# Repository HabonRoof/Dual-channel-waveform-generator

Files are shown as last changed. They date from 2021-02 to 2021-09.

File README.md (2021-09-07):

# 基於AD9833之雙通道直接數位合成波型產生器

## 簡介  

本專案使用AD9833直接數位信號合成器(Direct Digital Synthesizer)，利用數位方式產生任意波型與頻率。  
控制端使用與Arduino UNO相同之Atmega328P微處理器，顯示器使用128*64藍底白字LCD顯示器。  
This projec use AD9833 direct digital synthesizer to generate any waveform with any frequency.
Atmega328P as main controller, and the white blue LCD display shows the user interface.
使用方法:
首先透過LCD螢幕設定各通道之波型、頻率、相位等等參數，透過微處理器設定參數，再由AD9833產生對應之波型訊號。  
此訊號會再透過LM318 高轉動率(Slew Rate)運算放大器將電壓放大至+12V~-12V之振幅。  
此外，板載之+12、-12、5V電源使用線性穩壓器做為電源供應，提供乾淨無雜訊之直流電源，以避免市電雜訊干擾波型輸出。  
How to use:
Use the rotary encode to setup th ewaveform parameter, such as waveform type, frequency and phase, which progress to main uC, and generate the corresponding sugnal.
The signal will megnified by LM318 high slew-rate amplifier to +12V~-12V range.
Morevoer, the project use low dropout linear regulater to provide clar, noise-less power source.

## 波型展示
最高頻率輸出/Maximum frequency output  
12.5 MHz 輸出
最低頻率輸出  

正弦波/Sinusoidal wave  
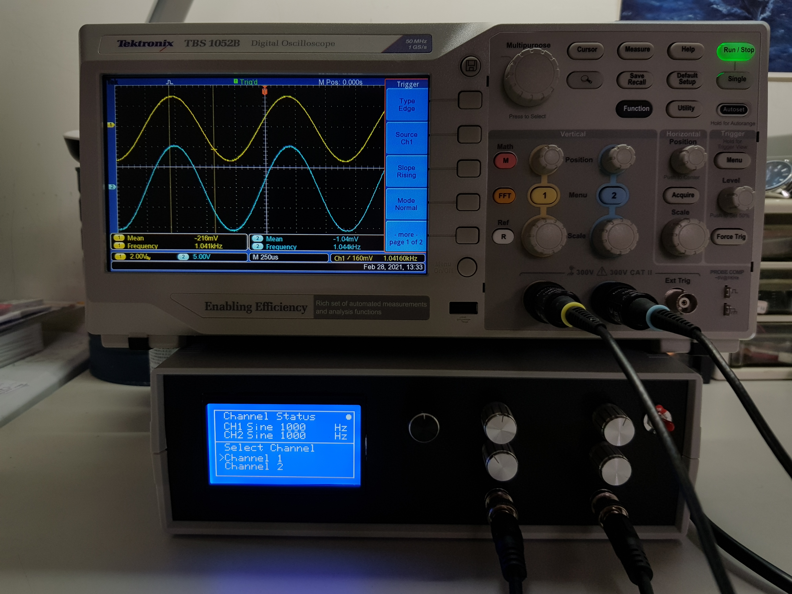
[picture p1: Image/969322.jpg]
6kHz 正弦波輸出

方波
1kHz 方波輸出
三角波/Truangular wave
1kHz 三角波輸出
主選單畫面/Main menu
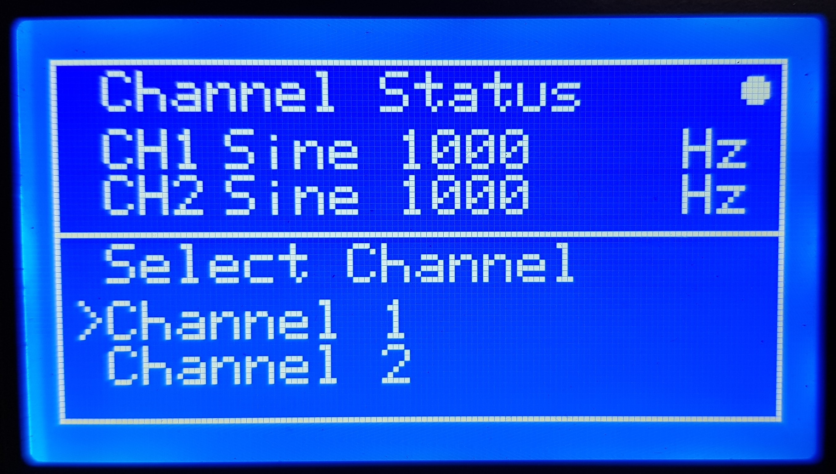
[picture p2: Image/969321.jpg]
通道輸出狀態以及主選單

通道1 設定選擇畫面/Channel1 setting
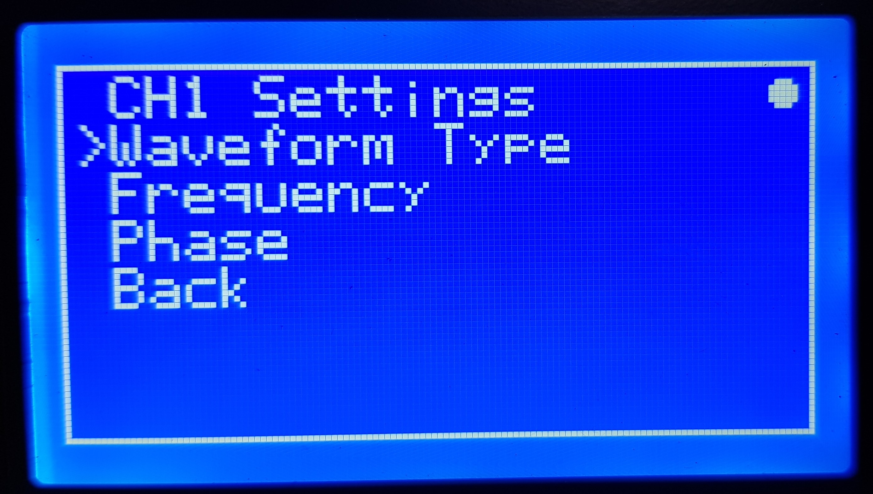
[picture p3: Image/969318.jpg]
Ch1 設定

波型選擇畫面/Waveform types
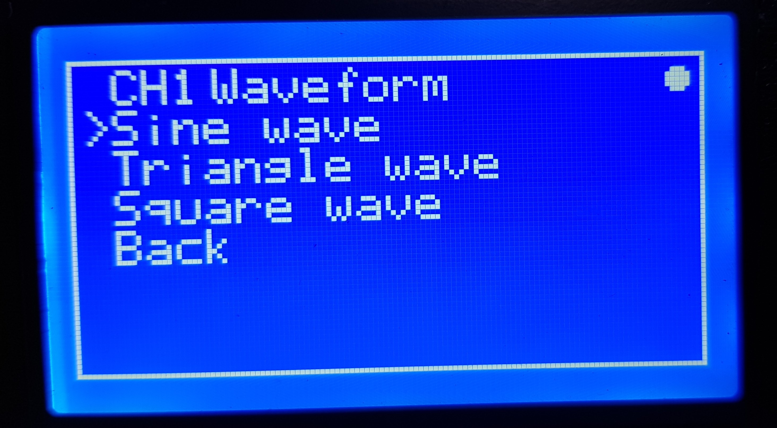
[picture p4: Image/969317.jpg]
CH1波型選擇

頻率設定畫面/Frequency setting
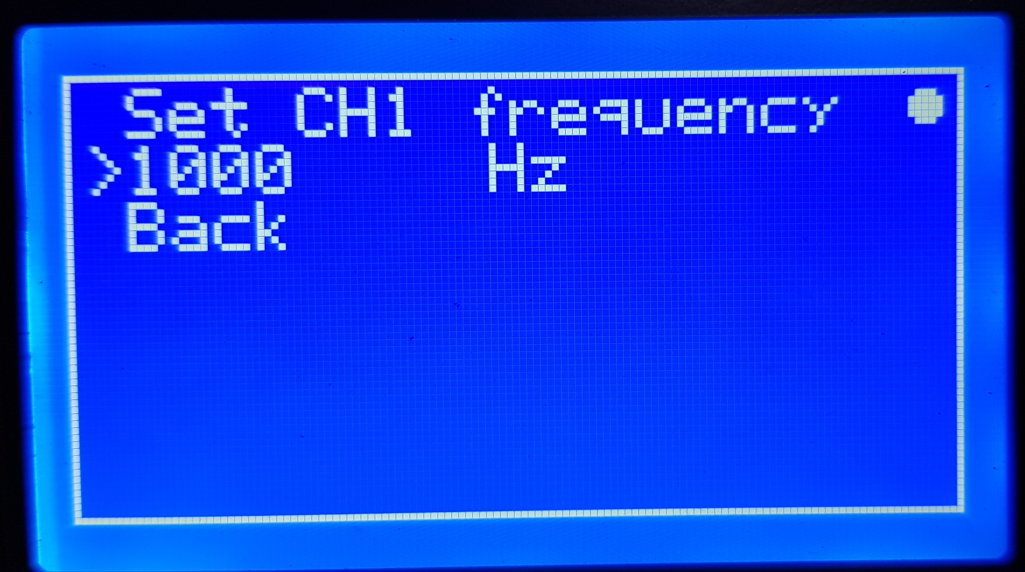
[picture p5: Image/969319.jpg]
Ch1頻率設定

頻率設定畫面-2/Frequency Setting
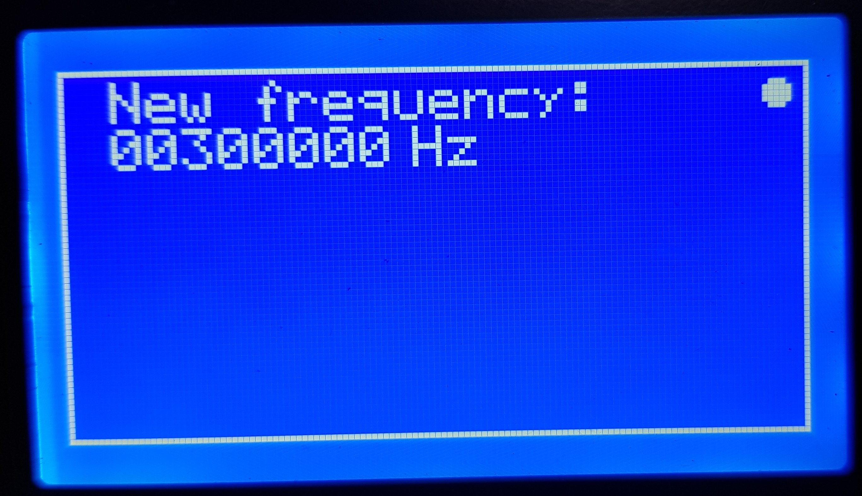
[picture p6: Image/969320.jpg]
Ch1頻率設定畫面-2


##材料表
AD9833 DDS Module x2   
Atmega328P x1  
LM318 運算放大器 x2  
12W 110/220V轉12Vac 變壓器 x1  
10k Ohm 可變電阻 x2  
100k Ohm 可變電阻 x2  
旋轉編碼器 x1  
開關 x2  
專案盒 x1  
電容器 x6  

## 硬體介紹
###AD9833 DDS 訊號產生器  
[維基百科-直接數位訊號合成](https://zh.wikipedia.org/wiki/%E7%9B%B4%E6%8E%A5%E6%95%B0%E5%AD%97%E5%90%88%E6%88%90)  
[Digikey-直接數位合成器-基本知識](https://www.digikey.tw/zh/articles/the-basics-of-direct-digital-synthesizers-ddss)  
直接數位訊號合成器基本原理就是使用內建的數位訊號表，紀錄不同訊號的波型振福， 
晶片讀取波型振福後，利用自身的類比數位訊號轉換器將資料轉換成實際電壓輸出，進而模擬出連續的類比訊號。  
然而，受限於最大系統時脈頻率，最高的模擬波型輸出頻率只有系統時脈頻率的1/2，此為奈奎氏頻率的限制，  
但可以更簡單的理解成在方波的情況下，波型有兩種狀況:最大與最小，而假設系統時脈頻率為fs，輸出頻率最大也只能到1/2 fs。  
DDS雖然可以透過查表產生不同波型，但其本質仍然是使用方波座數位訊號合成，因此在輸出波型中會含有系統時脈的諧波成分，  
要解決此問題需要在輸出端放置一低通濾波器將高頻諧波截去。此濾波器截止頻率需設定稍高於最大輸出頻率，即1/2 fs。
更詳細的原理可以參考上方超連結。  

###LM318 運算放大器  
電子電路中，運算放大器為常見的使用零件，但在基礎實習應用或比較器應用中，較不重視轉動率(Slew Rate)這項參數。  
此參數是評價運算放大器速度的重要指標，其定義為: 單位時間內可變化的電壓大小，單位為 V/uS。
在本專案一開始，使用LM358 作為訊號放大器，但其轉動率只有0.3V/uS，其較慢的轉動率使的DDS產生高頻訊號時，無法放大輸入訊號，導致輸出訊號震幅降低。  
後來改使用LM318訊號放大器後，其轉動率為70V/uS，此特性雖不足以滿足我們最高頻率12.5MHz，最大峰對峰值24V之設計，但可計算出在1MHz輸出下，電壓震幅可達7V之特性。  
這已經滿足大部分的應用需求了。  

###Atmega 328P 8位元微處理器  
大家熟悉的Arduino UNO就是使用這顆微控制器，本專案使用Atmega328P最精簡電路，並透過USB-TTL 燒錄器將程式碼燒錄進晶片中。  
Atmega最精簡電路只需要16MHz石英晶體震盪器、2x22pF陶瓷電容器、按鈕開關以及10k Ohm電阻即可建構。  
燒錄器可選擇任意USB5轉TTL串列埠訊號轉換器，在電腦端安裝好轉換器的驅動程式後，使用Arduino IDE燒錄時，當狀態是列顯示"上傳中" 時，按下重製按鈕便可將程式碼上傳至微處理機中。

###12864LCD液晶顯示器  
此液晶顯示器與市面上常見之128X64液晶顯示器稍微不同，因為是從對岸採購的，所以其函式庫

## 軟體介紹
firmware_v1.0 .ino  
第1.0版本波型產生器主要程式，

lcd_screens.ino  
液晶顯示器特定頁面  

lcdUI.h  
LCD目錄子函式，包含主目錄、通道設定、波型選擇、頻率選擇、相位選擇。  
此項目專攻coding的人看到會發瘋，因為我亂用class級別 QQ  
照理說可以再把這部分簡化，或者直接用子程式取代即可。  

## 已知問題
1. 此波型產生器之最高頻率為12.5MHz(方波，系統頻率為24MHz時)，受限於V1.0版本資料型態以及變數設置，最大只有10MHz，仍待改進。
2. 選單主畫面缺乏目前通道訊號狀態
3. 線性穩壓器溫度需要量測
4. V1.0版尚未支援波型相位設定
5. 實際輸出與設定值似乎有誤差，檢查lcdSetFrequency涵式

##改進目標
1. 功率消耗過高，浪費在線性穩壓器上
2. 硬體忘記留韌體燒錄孔 QwQ 每次都要拆開更新韌體

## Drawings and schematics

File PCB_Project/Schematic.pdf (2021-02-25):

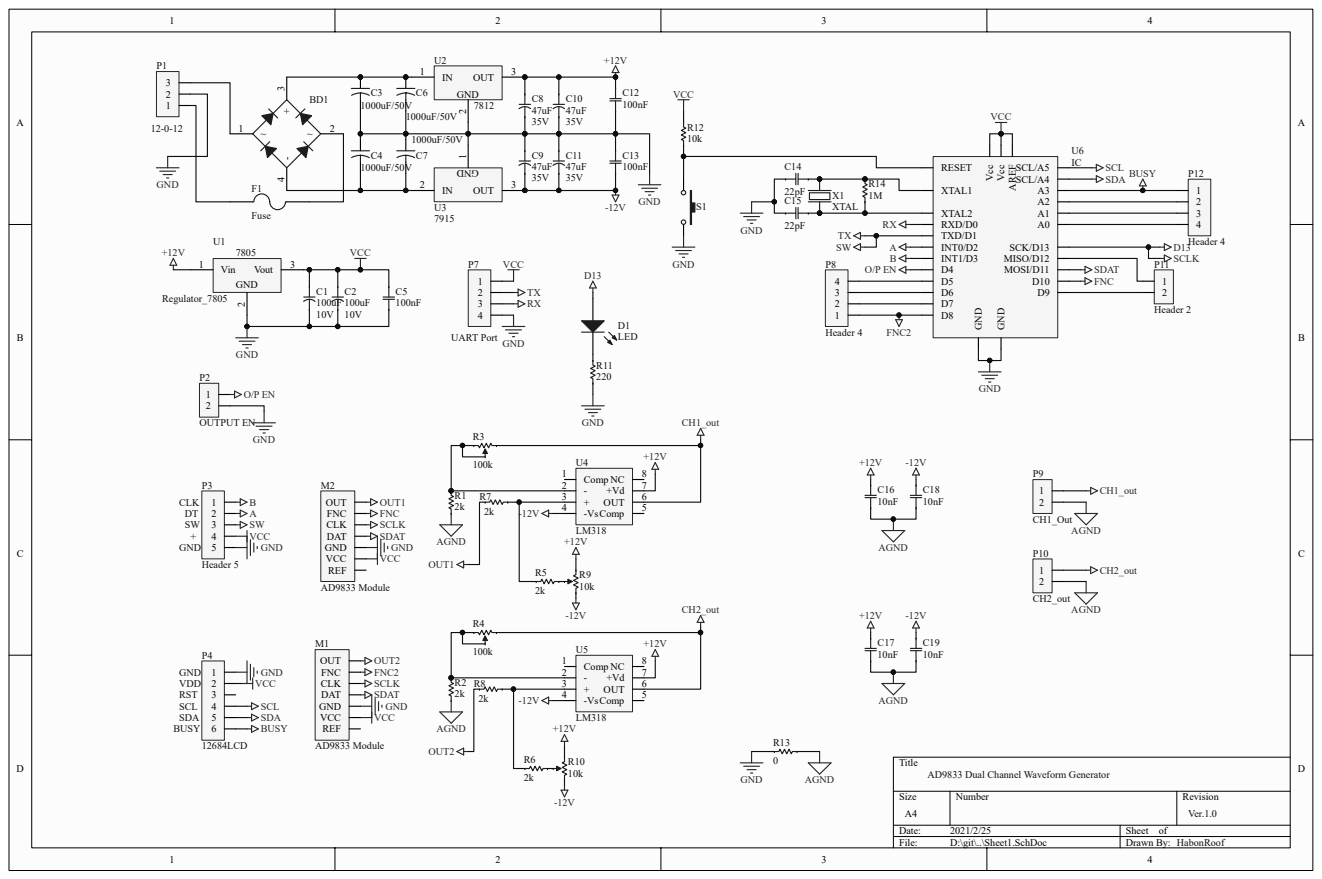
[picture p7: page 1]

Title
AD9833 Dual Channel Waveform Generator

Date: 2021/2/25 | Sheet of
File: D:\git\..\Sheet1.SchDoc | Drawn By: HabonRoof

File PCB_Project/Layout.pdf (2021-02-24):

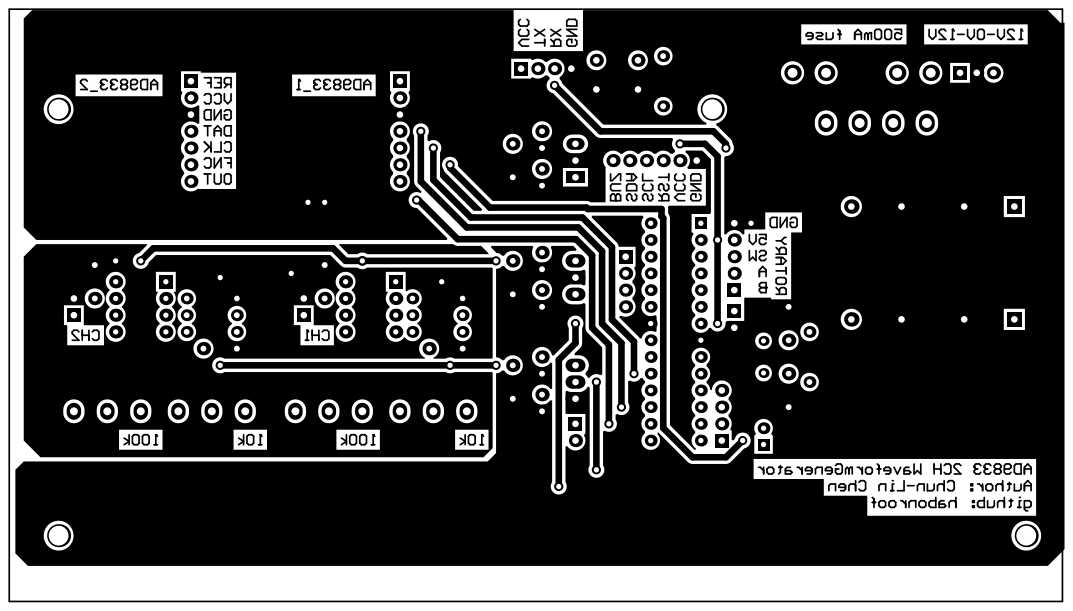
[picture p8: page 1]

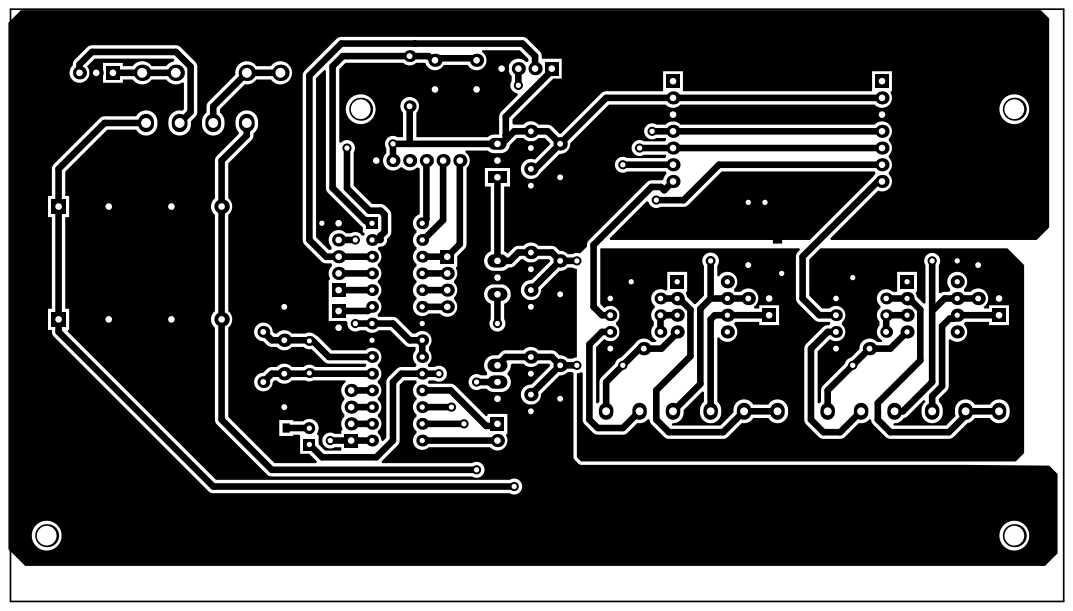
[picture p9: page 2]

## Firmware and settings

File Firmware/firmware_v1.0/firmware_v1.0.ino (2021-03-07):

/*
  This is a dual channel wave form generator firmware
  Use AD9833 DDS signal generator as main function IC
  Hardware schematic please visit @habonroof github

  Author: Chun-Lin Chen (HabonRoof)
  License: CC-BY 3.0

  Update: 2021/02/28
  Feature:Add channel status page at main menu
  Fix the accurate of frequency issue
  Add channel indicator on each setting screen to ensure user know which channel is he setting
  Issue:
  Phase function not avaliable
  The USB-TTL cable will interference the module signal, but not effect at output.
*/

#include <AD9833.h>         //Include AD9833 library from BillWilliams1952 @https://github.com/Billwilliams1952/AD9833-Library-Arduino
#include <RSCG12864B.h>     //Include RSCG12864 LCD module library. If you use another LCD, please modify the library as your LCD display.
#include <RotaryEncoder.h>  //Include awesome rotary encoder library from mathertel @https://github.com/brianlow/Rotary
#include "lcdUI.h"

//------------------ Pin configuration ----------------------

#define FNC_PIN     10      // Function pin of first AD9833 module
#define FNC_PIN2    8       // Function pin of second AD9833 module
#define Enable      4       // Enable output
#define Enter       1       // Rotary encoder button

RotaryEncoder encoder(2, 3);// Rotary encoder connect pin. I converte the pins into "pin change interrupt" mode to responce faster



//------------------- Create an AD9833 object ---------------

// Note, SCK and MOSI must be connected to CLK and DAT pins on the AD9833 for SPI
AD9833 gen(FNC_PIN, 24000000);       //Declare gen object as first AD9833 module
AD9833 gen2(FNC_PIN2, 24000000);     //Declare gen2 object as second AD9833 module

float ch1Freq = 1000.0;
float ch1Phase = 0;

float ch2Freq = 1000.0;
float ch2Phase = 0;
bool ad9833Update = false;

//--------------------- Serial Debug ------------------------

#define DEBUG  1    // 1:Enable Serial debugging 0:disable

//---------------------- Useful flags -----------------------

bool switchState = false;
bool lcdNeedUpdate = true;


//----------------------- UI variable ------------------------

int rotaryCtr = 0;
int buttonCtr = 0;
int oldButtonCtr = 0;
byte layer1Item = 0;
byte layer2Item = 0;
byte layer3Item = 0;
byte layer1Temp = 0;
byte layer2Temp = 0;
byte layer3Temp = 0;
bool back = false;
bool resetFlag = false;
bool setFreq = false;
bool setPhase = false;
float newFreq = 0.0;
byte ch1Waveform = 0;   //0 = sine, 1 = triangle, 2 = square
byte ch2Waveform = 0;

menuPage1 mainMenu;
menuPage2 channel;
menuPage3 waveform;
menuPage4 frequency;
menuPage5 phase;


void lcdShowMenu();
void lcdBootScreen();
void lcdAboutScreen();
void lcdSetFrequency();


//---------------------- Debounce --------------------------

unsigned long lastButtonPress = 0;
bool lastButtonState = true;
bool buttonState = true;

//---------------------- Sub function -----------------------

void ad9833Init();
void lcdBootScreen();   //Indicate the boot screen
void buttonChecker();   //Check the button and the rotary encoder
bool buttonPress();     //If button pressed, return true
void rotaryChecker();   //Check the rotary encoder value
void lcdShowMenu();
void ad9833Run();    //Update the AD9833 module for new configuration
void outputChecker();   //Check the output switch
void resetMenuItem();
unsigned long power();  //instead using pow()function because there is an error instead accurate value

//------------------------ ISR --------------------------------

ISR(PCINT2_vect) {
  encoder.tick();
}

//------------------------ Setup -----------------------------

void setup() {
#ifdef DEBUG
  Serial.begin(115200);
#endif

  PCICR   |= (1 << PCIE2);    // Enables Pin Change Interrupt 1 that covers the Analog input pins or Port C.
  PCMSK2  |= (1 << PCINT18) | (1 << PCINT19);  // This enables the interrupt for pin 2 and 3 of Port C.

  pinMode(Enable, INPUT_PULLUP);
  pinMode(Enter, INPUT);
  RSCG12864B.begin();
  RSCG12864B.brightness(255);
  RSCG12864B.clear();
  ad9833Init();
  lcdBootScreen();
  lastButtonPress = millis();   //Set last button press time to millis()
}

//----------------------- Main loop --------------------------------

void loop() {
  outputChecker();    // Enable oputput
  buttonChecker();
  rotaryChecker();
  lcdShowMenu();
  ad9833Run();
  resetMenuItem();
#ifdef DEBUG
  Serial.print("setFreq:");
  Serial.println(setFreq);
  Serial.print("oldButtonCtr:");
  Serial.println(oldButtonCtr);
  Serial.print("newFreq:");
  Serial.println(newFreq);
  Serial.print("buttonCtr:");
  Serial.println(buttonCtr);
  Serial.print("layer1Item:");
  Serial.println(layer1Item);
  Serial.print("layer2Item:");
  Serial.println(layer2Item);
  Serial.print("layer3Item:");
  Serial.println(layer3Item);
  Serial.println();
#endif
  delay(50);
}

void resetMenuItem() {
  if (resetFlag) {
    resetFlag = false;
    layer1Temp = 0;
    layer2Temp = 0;
    layer3Temp = 0;
    layer1Item = 0;
    layer2Item = 0;
    layer3Item = 0;
#ifdef DEBUG
    Serial.println("Reset menu item");
#endif
  }
}

void ad9833Run() {
  if (ad9833Update) {
    Serial.println("ad9833 update!!!");
    ad9833Update = false;
    if (layer1Item == 0) {
      if (layer2Item == 0) {
        //setting CH1 waveform type
        if (layer3Item == 0) {
          //CH1 sinewave
          gen.SetWaveform(REG0, SINE_WAVE);
          ch1Waveform = 0;
          resetFlag = true;
        }
        else if (layer3Item == 1) {
          //CH1 triangle wave
          gen.SetWaveform(REG0, TRIANGLE_WAVE);
          ch1Waveform = 1;
          resetFlag = true;
        }
        else {
          //CH1 square wave
          gen.SetWaveform(REG0, SQUARE_WAVE);
          ch1Waveform = 2;
          resetFlag = true;
        }
      }
      else if (layer2Item == 1) {
        //setting CH1 frequency
        if (layer3Item == 0) {
          gen.SetFrequency(REG0, ch1Freq);
          resetFlag = true;
        }
      }
      else {
        //setting CH1 phase
        gen.SetPhase(REG0, ch1Phase);
        //setPhase = true;
        resetFlag = true;
      }
    }
    else {
      if (layer2Item == 0) {
        //setting CH2 waveform type
        if (layer3Item == 0) {
          //CH2 sinewave
          gen2.SetWaveform(REG0, SINE_WAVE);
          ch2Waveform = 0;
          resetFlag = true;
        }
        else if (layer3Item == 1) {
          //CH2 triangle wave
          gen2.SetWaveform(REG0, TRIANGLE_WAVE);
          ch2Waveform = 1;
          resetFlag = true;
        }
        else {
          //CH2 square wave
          gen2.SetWaveform(REG0, SQUARE_WAVE);
          ch2Waveform = 2;
          resetFlag = true;
        }
      }
      else if (layer2Item == 1) {
        //setting CH2 frequency
        if (layer3Item == 0) {
          gen2.SetFrequency(REG0, ch2Freq);
          resetFlag = true;
        }
      }
      else {
        //setting CH2 phase
        gen2.SetPhase(REG0, ch2Phase);
        resetFlag = true;
      }
    }
  }
}

void lcdShowMenu() {
  if (buttonCtr == 0) //Channel select
    mainMenu.show(lcdNeedUpdate, rotaryCtr, layer1Temp, ch1Freq, ch2Freq, ch1Waveform, ch2Waveform);
  else if (buttonCtr == 1)  //Setting select
    channel.show(lcdNeedUpdate, rotaryCtr, layer2Temp, back, layer1Item);
  else if (buttonCtr == 2)  //channel waveform setting
    switch (layer2Item) {
      case (0):   //Waveform select
        waveform.show(lcdNeedUpdate, rotaryCtr, layer3Temp, back, layer1Item);
        break;
      case (1):   //Frequency setting
        frequency.show(lcdNeedUpdate, rotaryCtr, layer3Temp, back, layer1Item, ch1Freq, ch2Freq, setFreq, layer1Item);
        break;
      case (2):   //Phase setting
        phase.show(lcdNeedUpdate, rotaryCtr, layer3Temp, back);
        break;
    }
  else if (buttonCtr > 2) { //only frequency setting and phase setting can go into this case
    if (layer2Item == 1) {
      Serial.println("frequency hertz");
      lcdSetFrequency();

      if (buttonCtr > 11) { //reset buttonCtr when done freq setting
        buttonCtr = 0;
        ad9833Update = true;
      }
    }
    else if (layer2Item == 2) {
      Serial.println("phase degree");

      if (buttonCtr > 5) { //reset buttonCtr when done phase setting
        buttonCtr = 0;
        ad9833Update = true;
      }
    }
    else {
      buttonCtr = 0;
      ad9833Update = true;
    }
  }
}


void rotaryChecker() {
  RotaryEncoder::Direction currentDirection = encoder.getDirection();
  if (currentDirection == RotaryEncoder::Direction::COUNTERCLOCKWISE)
    rotaryCtr--;
  else if (currentDirection == RotaryEncoder::Direction::CLOCKWISE)
    rotaryCtr++;
}


void buttonChecker() {
  if (buttonPress()) {
    buttonState = false;
    layer1Item = layer1Temp;    //Update layerItem to layerTemp when press button
    layer2Item = layer2Temp;
    layer3Item = layer3Temp;
    buttonCtr ++;
    if (back) {
      buttonCtr = buttonCtr - 2;
      back = false;
      lcdNeedUpdate = true;
    }
  }
}



void lcdSetFrequency() {
  float oldFreq = 0.0;
  byte xPos = 9;

  if (lcdNeedUpdate && !setFreq) {
    RSCG12864B.clear();
    rotaryCtr = 0;
    RSCG12864B.draw_rectangle(0, 0, 127, 63);    //Draw outline rectangle
    RSCG12864B.print_string_5x7_xy(9, 2, "New frequency:");
    if (layer1Item == 0)
      oldFreq = ch1Freq;
    else if (layer1Item == 1)
      oldFreq = ch2Freq;
    RSCG12864B.print_string_5x7_xy(9, 10, "00000000"); 	//clear oldFreq screen
    RSCG12864B.print_string_5x7_xy(60, 10, "Hz");
    setFreq = true;
    lcdNeedUpdate = false;
  }

  if (rotaryCtr > 9)
    rotaryCtr = 0;
  else if (rotaryCtr < 0)
    rotaryCtr = 9;

  if ((buttonCtr < 11) && setFreq) {
    xPos = xPos + ((buttonCtr - 3) * 6);
    RSCG12864B.cursor(xPos, 10);
    RSCG12864B.print_U32_5x7(rotaryCtr);
    RSCG12864B.delete_line(xPos-6,17,xPos,17);
    RSCG12864B.draw_line(xPos,17,xPos+4,17);
    if (buttonCtr != oldButtonCtr) { //When buttonCtr change, update newFreq once
      oldButtonCtr = buttonCtr;  //Update oldButtonCtr
      newFreq = newFreq + rotaryCtr * power(10, (11 - buttonCtr));
      Serial.print("New Frequemcy:");
      Serial.println(newFreq);
    }
  }
  if (buttonCtr == 11) {
    if (lcdNeedUpdate) {
      RSCG12864B.clear();
      lcdNeedUpdate = false;
      newFreq = newFreq + rotaryCtr * power(10, (11 - buttonCtr));
      RSCG12864B.draw_rectangle(0, 0, 127, 63);    //Draw outline rectangle
      if (layer1Item == 0)
        RSCG12864B.print_string_5x7_xy(9, 2, "Set CH1 freq to");
      else if (layer1Item == 1)
        RSCG12864B.print_string_5x7_xy(9, 2, "Set CH2 freq to");
      RSCG12864B.print_U32_5x7_xy(9, 10, newFreq);  //clear oldFreq screen
      RSCG12864B.print_string_5x7_xy(60, 10, "Hz");
    }
  }
  if (buttonCtr > 11) {
    if (layer1Item == 0)
      ch1Freq = newFreq;
    else if (layer1Item == 1)
      ch2Freq = newFreq;
    oldButtonCtr = 0;
    newFreq = 0;
    ad9833Update = true;
    resetFlag = true;
    setFreq = false;
  }
}

bool buttonPress() {
  if ((millis() - lastButtonPress) > 100) {
    if (digitalRead(Enter) != lastButtonState) {
      buttonState = digitalRead(Enter);
      lastButtonState = buttonState;
      lastButtonPress = millis();
      if (buttonState == LOW) {
        lcdNeedUpdate = true;
        return true;
      }
    }
  }
  return false;
}

void ad9833Init() {
  gen.Begin();
  gen2.Begin();
  gen.ApplySignal(SINE_WAVE, REG0, 1000);
  gen2.ApplySignal(SINE_WAVE, REG0, 1000);
}

void outputChecker() {
  if (!digitalRead(Enable)) {
    gen.EnableOutput(true);   // Turn ON the output
    gen2.EnableOutput(true);
    RSCG12864B.draw_fill_circle(122, 5, 2);
  }
  else {
    gen.EnableOutput(false);   // Turn OFF the output
    gen2.EnableOutput(false);
    RSCG12864B.delete_fill_circle(122, 5, 2);
  }
}

unsigned long power(int base, int exponent) {
  unsigned long result;
  if (exponent == 0) {
    result = 1;
  } else {
    result = base;
    for (int i = 0; i < (exponent - 1); i++) {
      result *= base;
    }
  }
  return result;
}

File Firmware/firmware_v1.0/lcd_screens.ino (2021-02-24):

/*LCD screen code for 2CH waveform generator

*/

//------------------------ Boot ------------------------

void lcdBootScreen() {
  RSCG12864B.clear();
  RSCG12864B.print_string_16_xy(24, 0, "AD9833 2CH");
  RSCG12864B.print_string_16_xy(32, 16, "Waveform");
  RSCG12864B.print_string_16_xy(24, 32, "Generator");
  RSCG12864B.print_string_16_xy(24, 48, "Ver. 1.0.0");
  delay(1000);
  RSCG12864B.draw_rectangle(0, 0, 127, 63);
}

//------------------------ About ------------------------

void lcdAboutScreen() {
  if (lcdNeedUpdate) {
    lcdNeedUpdate = false;
    RSCG12864B.clear();
    RSCG12864B.print_string_5x7_xy(3, 8, "AD9833 Waveform");
    RSCG12864B.print_string_5x7_xy(3, 16, "Generator");
    RSCG12864B.print_string_5x7_xy(3, 24, "Author: HabonRoof");
    RSCG12864B.print_string_5x7_xy(3, 32, "https//:habonroof/");
    RSCG12864B.print_string_5x7_xy(3, 40, "2CHWaveformGenerator");
  }
}

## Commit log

2021-02-24 Upload firmware and PCB file
    [PCB1.PcbDoc, PCB2.PcbDoc, PCB_Project.PrjPcb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]
2021-02-25 modify Readme
    [PCB1.PcbDoc, Sheet1.SchDoc]
2021-02-25 Modify files
    [Sheet1.SchDoc]
2021-02-28 Add channel indicator, Fix frequency accuracy, Add main menu channel status, modify some code
    [firmware_v1.0.ino, lcdUI.h]
